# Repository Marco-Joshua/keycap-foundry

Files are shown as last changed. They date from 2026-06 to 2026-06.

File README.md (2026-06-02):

# Keycap Foundry

Parametric MX-compatible keycap library designed for **lost-wax silver casting**.
Written in OpenSCAD, validated with `trimesh`, previewed in a Three.js gallery.

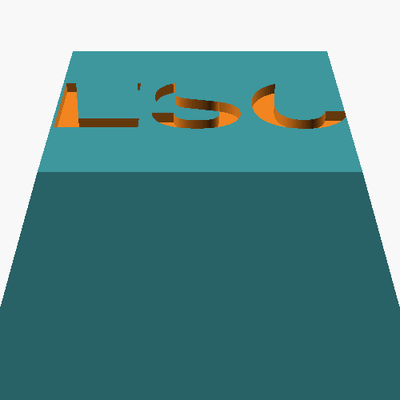
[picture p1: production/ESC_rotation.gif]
ESC keycap rotation


## 사용법 (한국어 요약)

OpenSCAD 기반 파라메트릭 실버 키캡 라이브러리. **MX 호환 키캡을 코드 한 줄 바꿔서 다시 뽑고, 화면에서 보고, 주물업체에 보낼 STL/도면까지 한 번에 만들어줍니다.**

### 1. 설치 (최초 1회)
```bash
brew install --cask openscad@snapshot           # ARM Mac 네이티브
python3 -m pip install --user numpy trimesh
```

### 2. 갤러리에서 미리 만들어진 디자인 보기
```bash
python3 -m http.server 8765
# 브라우저에서 http://localhost:8765/ 열기
```
- **ESC 키캡 (production)** 탭 — 본 발주용. 1.0mm wall(안전)·0.8mm wall(절감) 비교
- **평평한 윗면** 탭 — 같은 디자인 다른 벽 두께
- **단면 (내부 구조)** 탭 — 무광 + 검은 엣지로 내부 구조 시각화
- 하단 뷰 버튼으로 **정면·위·아래·옆** 전환 가능

### 3. 새 키캡 만들기
`keycap.scad`는 안 만지고 변수만 바꿔서 호출하면 됩니다:
```bash
# 예: "Enter" 2.25u, 1.0mm wall, 평평한 윗면, hollow, 캐스팅 보정 1.8%
openscad \
  -D 'flat_top=true' -D 'hollow=true' -D 'wall_thickness=1.0' \
  -D 'profile="cherry"' -D 'row=2' -D 'key_units=2.25' \
  -D 'legend="Enter"' -D 'legend_size=4.5' \
  -D 'shrink_compensation=1.018' \
  -o Enter_cast.stl keycap.scad
```
주요 변수는 아래 [Key parameters](#key-parameters-keycapscad) 표 참고.

### 4. STL 검증 + 실버 무게·원가 계산
```bash
python3 analyze.py Enter_cast.stl
# → manifold 확인, 부피, 925/999 무게, 예상 재료비 (₩1,500/g 기준)
```

### 5. 주물업체에 보낼 것
| 파일 | 용도 |
|---|---|
| `production/spec_sheet.html` | 브라우저에서 ⌘+P → PDF로 저장 → A4 도면 |
| `production/*_cast.stl` | **이 파일을 발주** (1.8% 업스케일 = 캐스팅 후 실치수) |
| `production/ESC_rotation.gif` | 카톡으로 "이런 거 가능한가요?" 미리보기 |

### 6. 디자인 바꾸고 갤러리에 반영
```bash
# 새 STL을 out/ 또는 production/에 넣고
python3 build_manifest.py    # → manifest.json 다시 빌드
# 브라우저 새로고침
```
갤러리에 노출할 항목은 `build_manifest.py`의 `ITEMS` 리스트에 추가합니다.

### 캐스팅 흐름
**시험 (PLA 출력)** → 동네 출력소 ₩3~5천, `*_design.stl` 사용, 키보드에 끼워봄
↓
**견적 의뢰** → 종로 주얼리 거리 주물업체, `*_cast.stl` + spec sheet PDF + GIF 전달
↓
**본 발주** → 캐스터블 레진 출력 → 로스트왁스 → 폴리싱 → (선택) 로듐 도금

---

## What this is

A code-defined keycap that you can:
- regenerate at any size (1u, 1.25u, ..., 6.25u spacebar)
- engrave with any text (currently Helvetica Bold, easily swappable)
- hollow with a uniform wall (default 1.0 mm, configurable down to 0.8 mm)
- export as a watertight, manifold STL ready for casting

The included `production/` folder ships an **ESC keycap** (1u, flat top, Cherry R1
height, Hollow 1.0mm wall) — both at design dimensions and with **+1.8% shrink
compensation** applied for silver lost-wax casting.

## Why parametric over CAD

Keycaps need precision (the MX cross slot is 0.05 mm tolerance) but very little
artistic curvature. That makes them a perfect fit for code-defined modelling:
change a variable, rebuild in 100 ms. No CAD license, no GUI clicks.

## Layout

```
keycap.scad          Parametric library (single file, all features)
analyze.py           STL → manifold check + volume + silver weight + cost
build_manifest.py    Regenerate manifest.json for the gallery
gallery.html         Three.js viewer with 4 view presets (front/top/bottom/iso)
index.html           Landing page → links to gallery, spec sheet, GIF, slicer guide
out/                 Generic flat-top hollow demos (1.0 & 0.8 mm wall)
production/          ESC keycap deliverable set
  ├── *_design.stl   Exact dimensions — for slicer / PLA test print
  ├── *_cast.stl     +1.8% upscale — what you give to the silver caster
  ├── *_cutaway.stl  Half-section for showing internal structure
  ├── spec_sheet.html  Printable A4 dimension drawing (browser → PDF)
  ├── ESC_rotation.gif  3-second 360° preview
  ├── ESC_SPEC.md    Plain-text spec (for email body)
  └── SLICER_CHECK.md  Pre-print checklist for FDM / resin
```

## Quick start

```bash
# Prerequisites
brew install --cask openscad@snapshot      # ARM-native OpenSCAD
python3 -m pip install --user numpy trimesh

# Generate an ESC keycap
openscad \
  -D 'flat_top=true' -D 'hollow=true' -D 'wall_thickness=1.0' \
  -D 'profile="cherry"' -D 'row=1' -D 'legend="ESC"' -D 'legend_size=4.5' \
  -o ESC.stl keycap.scad

# Validate + estimate silver weight & cost
python3 analyze.py ESC.stl

# Preview the gallery
python3 -m http.server 8765
# → open http://localhost:8765/
```

## Key parameters (`keycap.scad`)

| Parameter | Default | Notes |
|---|---|---|
| `key_units` | `1.0` | 1, 1.25, 1.5, 1.75, 2, 2.25, 6.25 |
| `profile` | `"cherry"` | `cherry` · `oem` · `sa` · `dsa` · `xda` |
| `row` | `3` | R1..R4 — only affects height on sculpted profiles |
| `hollow` | `false` | Open-bottom hollow shell with + stem |
| `wall_thickness` | `1.0` | Uniform wall (sides + top); 0.6 mm castable minimum |
| `flat_top` | `false` | Override the profile dish for a fully flat top |
| `legend` | `""` | Text to engrave (empty = none) |
| `legend_size` | `7` | Font height in mm |
| `legend_depth` | `0.45` | Engrave depth in mm |
| `shrink_compensation` | `1.0` | Use `1.018` for silver casting (1.8% upscale) |
| `cutaway` | `false` | Slice in half along XZ plane (for visualization) |

## Casting workflow

1. Open `production/spec_sheet.html` in a browser, print → PDF.
2. PLA-print `*_design.stl` at a local print shop (~₩3–5k) → fit on an MX
   switch, verify dimensions.
3. Hand the silver caster the `*_cast.stl` file + the spec sheet PDF.
   Common path in Korea: 종로 주얼리 거리's lost-wax casters (₩20–50k/cap
   casting fee on top of silver material cost).
4. Optional: rhodium plating to prevent tarnish (~₩5–10k/cap).

## Design choices

- **Open bottom** — required so wax can drain during burnout and silver can
  fill cleanly. Also standard for injection-molded keycaps.
- **+-shaped stem with no end caps** — minimum material, matches the standard
  4-pillar layout you see in commercial cast/plated keycaps.
- **Uniform wall** — top wall follows the dish curve (or stays flat) so the
  wall is exactly `wall_thickness` everywhere — easier for casters to quote.
- **Cross slot extended to underside of top wall** — saves material in the
  stem while still grabbing the MX switch via the full 4 mm cross arms.

## License

MIT — see [LICENSE](LICENSE). Use, modify, sell, fork — go ahead.

## Acknowledgements

- Reference for MX dimensions and standard keycap construction:
  [rsheldiii/KeyV2](https://github.com/rsheldiii/KeyV2)
- Built with Claude Code (Opus 4.7) — see commit log for the design iteration.

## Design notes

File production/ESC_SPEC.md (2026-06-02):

# ESC 키캡 발주 명세 (Silver)

## 기본 정보
| 항목 | 값 |
|---|---|
| **키** | ESC |
| **각인** | "ESC" (음각, 4.5mm Helvetica Bold, 0.45mm 깊이) |
| **소재** | 순은 (999) 또는 스털링 실버 (925) |
| **마감** | 폴리싱 + (선택) 로듐 도금 |
| **공법** | Lost-wax casting |

## 치수 (최종 캐스팅 후 기준)
| 항목 | 값 |
|---|---|
| 가로 × 세로 | 18.10 × 18.10 mm (1u, Cherry profile) |
| 높이 | 9.40 mm (Cherry Row 1, F-row 호환) |
| 윗면 | **평평** (dish 없음) |
| 벽 두께 | 1.0 mm (균일, 측면·천장 모두) |
| Stem | + 자형, 4개 코너 필러 구조 (사진/사출 표준) |
| 십자 슬롯 | 4.10 × 1.27 mm, 깊이 ~5.5mm (top wall 직전까지) |
| 바닥 | 개방 (왁스 배출 가능) |

## 무게 / 원가
| 항목 | Sterling (925) | Fine (999) |
|---|---|---|
| 무게 | 7.83 g | 7.91 g |
| 재료비 (₩1,500/g 기준) | ≈ ₩11,750 | ≈ ₩11,870 |
| + 캐스팅·후처리 (예상) | ₩20,000 ~ ₩50,000 | — |

## 캐스팅 수축 보정
- **DESIGN STL**: 정확한 최종 치수 (18.10mm, 9.40mm). 3D 프린트 검증·MX 스위치 적합성 확인용.
- **CAST STL**: 1.8% 업스케일 (18.43mm, 9.57mm). 주물업체에 이 파일로 발주. 캐스팅 수축 후 DESIGN 치수로 수렴.

## 파일
| 파일 | 용도 |
|---|---|
| `ESC_1u_flat_hollow_1.0mm_design.stl` | 슬라이서 검증·시험 출력·MX 호환성 |
| `ESC_1u_flat_hollow_1.0mm_cast.stl` | 캐스터블 레진 출력 → 주물 의뢰 |
| `ESC_1u_cutaway.stl` | 내부 구조 설명용 (단면) |
| `preview_iso.png` | 아이소뷰 (캡 전체) |
| `preview_top.png` | 톱뷰 ("ESC" 각인 확인) |
| `preview_bottom.png` | 바텀뷰 (+ stem, 4개 코너 필러) |
| `preview_cutaway.png` | 단면도 (내부 캐비티) |

## 메시 검증
- ✅ Watertight (수밀)
- ✅ Manifold (매니폴드)
- ✅ Volume valid (부피 계산 정상)

## 주물업체에 전달 시 핵심 포인트
1. **벽 두께 1.0mm 균일** — 모든 wall이 1mm. 캐스팅 한계 안에 있음
2. **바닥 개방형** — 왁스 배출 + 사일버 주입 둘 다 용이
3. **십자 슬롯 dimensions**: 4.10 × 1.27 × 4.0mm 깊이 — Cherry MX 호환
4. **수축 보정 STL** 사용 (`_cast.stl` 파일)
5. 후처리: 십자 슬롯 내부 폴리싱 주의 (스위치 결합 부위)

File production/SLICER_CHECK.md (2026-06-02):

# 슬라이서 검증 가이드 (PLA·캐스터블 레진 출력 전)

## 빠른 체크 (5분)

### 1. 슬라이서에 STL 열기
- **PLA 출력 (시험용, FDM)**: Bambu Studio · Prusa Slicer · Cura
- **캐스터블 레진 출력 (주물용, SLA/DLP)**: Chitubox · Lychee Slicer · Bambu Studio (Bambu Lab A1/X1 + 레진 어댑터)

파일: `ESC_1u_flat_hollow_1.0mm_design.stl` (시험용) 또는 `_cast.stl` (수축 보정본)

### 2. 자동 점검할 항목
| 점검 | 정상 기준 | 문제 신호 |
|---|---|---|
| **Manifold (수밀성)** | "No errors" / 초록 체크 | "Non-manifold edges" 빨간 경고 → STL 손상 |
| **Wall thickness** | 1.0 mm 균일 | 0.4 mm 이하 영역 발견 시 강도 부족 경고 |
| **Inverted normals** | 없음 | 보라색/뒤집힌 면 있으면 STL 손상 |
| **Mesh repair** | "No repair needed" | "Auto-repair" 메시지 뜨면 우리 STL 문제 — 다시 export 필요 |

### 3. 출력 방향 (Orientation)
- **권장**: 바닥(MX 십자 슬롯)이 **위쪽**을 향하게 거꾸로 세움
  - 이유: 바닥이 개방형이라 서포트 거의 불필요, 윗면(ESC 각인)은 빌드 플레이트 쪽이라 매끈히 출력됨
- 측면 출력은 비추천 (사면이 모두 경사라 서포트 많이 필요)

### 4. 서포트 설정
- **FDM (PLA)**: 십자 슬롯 안쪽에 미세한 서포트 자동 생성될 수 있음. 출력 후 제거 가능
- **레진 (캐스터블)**: 외부 표면에만 가는 서포트 (0.4mm), 매끈한 면은 위쪽으로

### 5. 인쇄 설정 권장
**FDM 시험 출력 (PLA)**:
- Nozzle: 0.4 mm
- Layer: 0.16 mm
- Walls: 4 perimeters (실리콘 키캡과 흡사한 두께감)
- Infill: 25% (시험용이므로 가벼우면 됨)
- Time: ~30분 ~ 1시간 / cap

**캐스터블 레진 (주물 의뢰용)**:
- Layer: 0.05 mm (정밀)
- Resin: 캐스터블 (Castable wax-based) — Phrozen Wax Resin / Siraya Tech Cast
- 출력 후 burnout 가능한 잔여물 없는 종류
- Time: ~1시간 / cap

## 예상되는 경고 & 대응

| 경고 | 의미 | 대응 |
|---|---|---|
| "Wall under 0.5mm" | 일부 구간 wall thin | 우리 디자인은 0.7mm 최소 — 무시 OK |
| "Overhangs detected" | 일부 면이 45° 이상 경사 | 측면 경사 (top_inset 3mm) — 서포트 자동 처리 |
| "Multiple shells" | 분리된 메시 발견 | + stem의 4 pillar는 top wall로 연결되어 있음 — 정상 |
| "Mesh has gaps" | 진짜 STL 손상 | 우리 STL은 watertight 검증됨 — 다시 export |

## 확인 후 다음 단계

✓ 슬라이서 통과 → PLA 시험 출력 또는 캐스터블 레진 출력 의뢰
✗ 경고 떠도 무시 가능한 항목이면 진행, 아니면 keycap.scad에서 파라미터 조정 후 re-export

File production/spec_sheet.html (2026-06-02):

# ESC 키캡 — Silver Cast 발주 명세서

Cherry MX 호환 · 1u Row-1 · 평평한 윗면 · Hollow · Lost-Wax 캐스팅

키ESC

사이즈1u (18.10 × 18.10 mm)

높이9.40 mm (Cherry R1)

윗면평평 (no dish)

벽 두께1.0 mm 균일

Stem+ 4-pillar (MX 표준)

소재순은(999) 또는 스털링(925)

공법Lost-wax casting

예상 무게7.91 g (999)

재료비 (₩1,500/g)≈ ₩11,800

캐스팅 수축 보정+1.8% (설계 STL 포함)

마감폴리싱 · (선택) 로듐 도금

## 도면 — 4면 + 단면

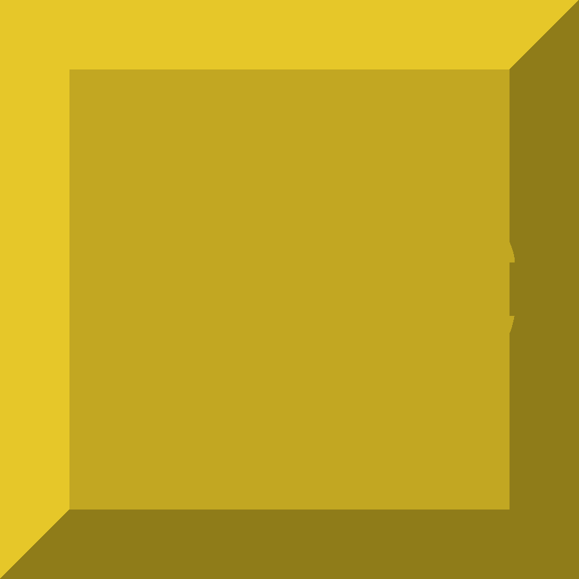
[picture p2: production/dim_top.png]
Top


TOP (위에서)

18.10 × 18.10 mm

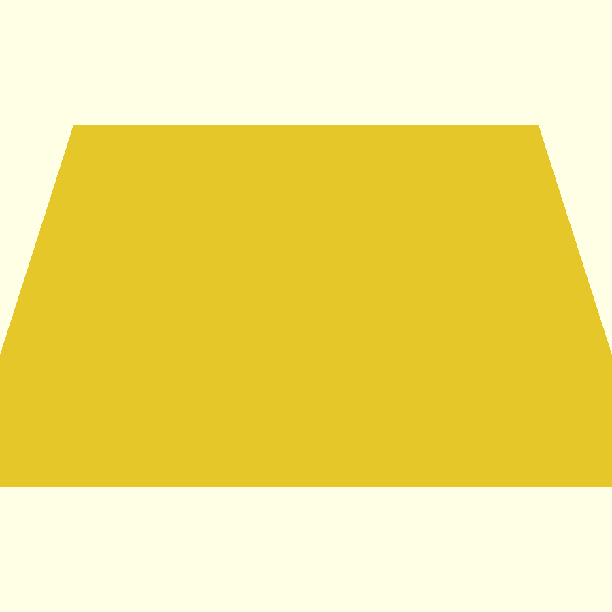
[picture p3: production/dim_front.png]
Front


FRONT (정면)

높이 9.40 mm

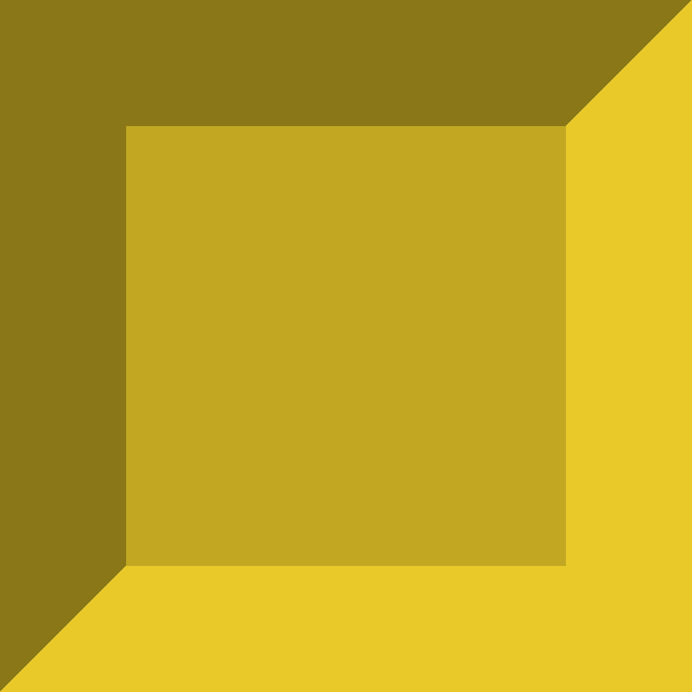
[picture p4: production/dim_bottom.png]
Bottom


BOTTOM (아래에서)

+ stem, 십자 슬롯

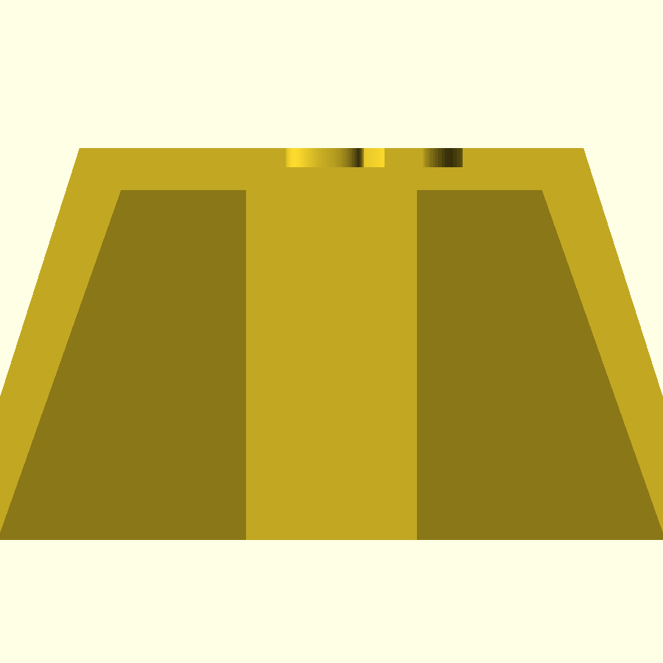
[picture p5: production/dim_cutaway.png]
Section


SECTION (단면)

wall 1.0 mm 균일

## 주요 치수 (Cast 후 최종 목표)

항목 | 설계값 | Cast STL (1.8%↑) | 비고
가로 (X) | 18.10 mm | 18.43 mm | 1u 표준 키 피치 19.05 − gap 0.95
세로 (Y) | 18.10 mm | 18.43 mm | 1u 표준
높이 (Z) | 9.40 mm | 9.57 mm | Cherry profile R1 (F-row 매칭)
윗면 사이즈 | 12.10 × 12.10 mm | 12.32 × 12.32 mm | top inset 3.0 mm
측면·천장 벽 두께 | 1.00 mm | 1.02 mm | 전체 균일
각인 "ESC" | 4.5 mm font, 0.45 mm 깊이 | − | Helvetica Bold, 음각
MX 십자 슬롯 (장) | 4.10 mm | 4.17 mm | Cherry MX stem 4.0 mm + 여유 0.10
MX 십자 슬롯 (단) | 1.27 mm | 1.29 mm | MX stem 1.17 mm + 여유 0.10
십자 슬롯 깊이 | ~5.5 mm | ~5.6 mm | 천장 wall까지 (0.4 mm 캡 잔류)
Stem boss 외곽 (장) | 4.10 mm | 4.17 mm | + 4-pillar 구조
Stem boss 외곽 (단) | 2.67 mm | 2.72 mm | 슬롯 양옆 wall 0.70 mm
바닥 | 개방 | 개방 | 왁스 배출 가능

## 캐스팅 작업 메모

- 발주 시 사용 파일: ESC_1u_flat_hollow_1.0mm_cast.stl (수축 보정본)
- 벽 두께 1.0 mm는 925 sterling silver lost-wax 캐스팅 가능 범위 내. 부분적으로 0.7 mm까지 좁아지는 십자 슬롯 옆 wall이 가장 얇은 부분 — 무리 없이 가능.
- 바닥 개방형이므로 왁스/레진 배출 + 은 주입에 별도 vent 불필요.
- 후처리: 외부 폴리싱 후, MX 십자 슬롯 내부는 폴리싱하지 말 것 (스위치 결합 부위, 표면 다소 거칠어야 그립 양호).
- 치수 검증: 캐스팅 후 십자 슬롯 사이즈 (4.0 × 1.17 mm 이상 1.20 × 4.05 이하) 확인 필요. 너무 빡빡하면 MX 스위치 결합 어렵고, 너무 헐거우면 키캡 뽑힘.
- 변색 방지: 손가락 접촉 면이라 시간 지나면 황변 가능. 로듐 도금 권장 (캡당 ₩5,000~10,000 추가).

## 파일 (production/)

ESC_1u_flat_hollow_1.0mm_design.stl슬라이서 검증·PLA 시험 출력·MX 호환성 확인용

ESC_1u_flat_hollow_1.0mm_cast.stl★ 주물업체 발주용 (1.8% 업스케일)

ESC_1u_cutaway.stl내부 구조 설명용 (단면)

ESC_1u_flat_hollow_0.8mm_design.stl대안: 더 얇은 벽 (6.60g)

ESC_1u_flat_hollow_0.8mm_cast.stl대안 발주용

ESC_rotation.gif360° 회전 미리보기 (캐스터에 카톡 전송용)

생성: OpenSCAD 2026.04.26 → STL (manifold, watertight 검증) → trimesh 분석

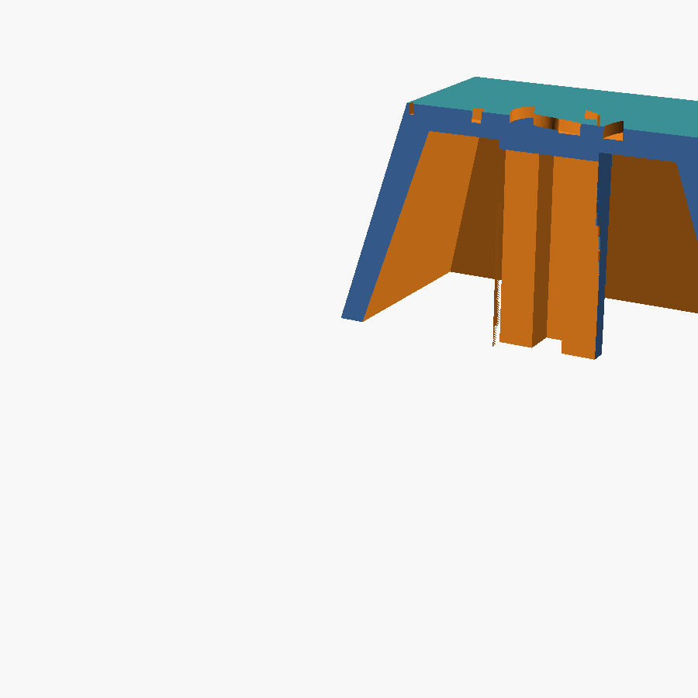
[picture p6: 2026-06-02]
production/preview_cutaway.png

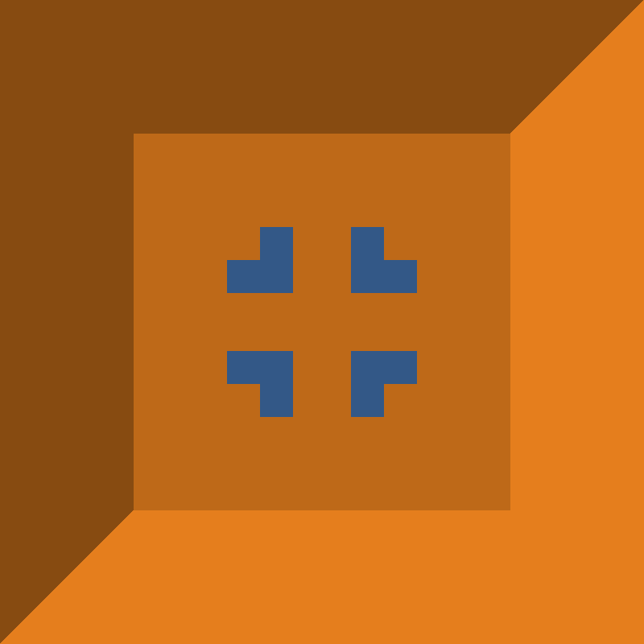
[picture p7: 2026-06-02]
production/preview_bottom.png

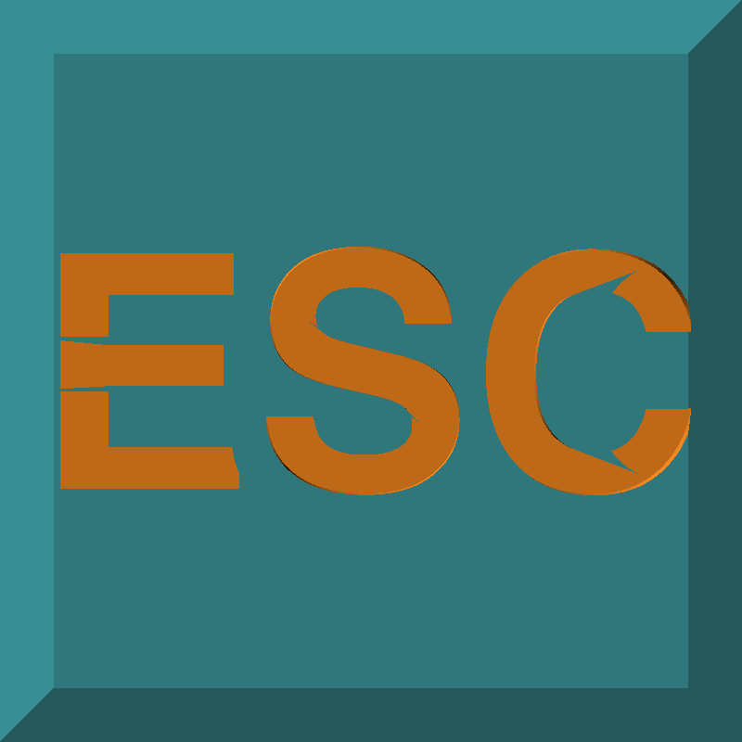
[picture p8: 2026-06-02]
production/preview_top.png

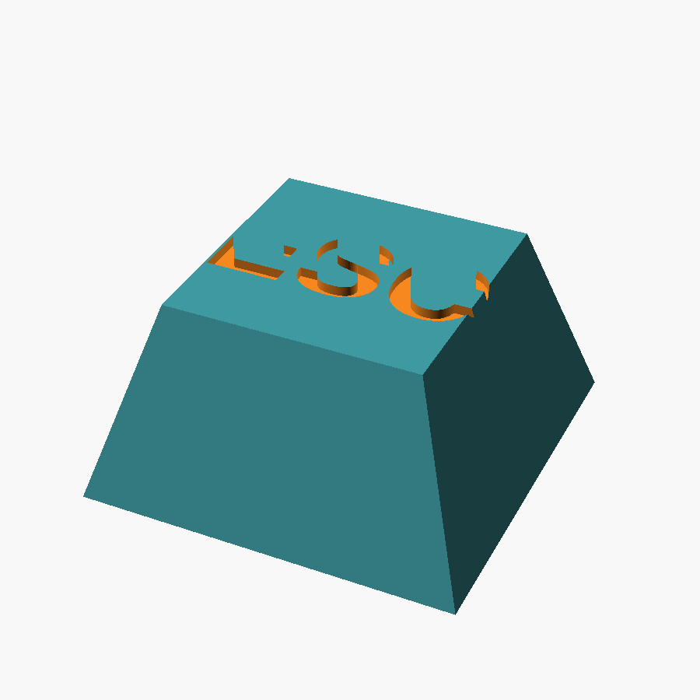
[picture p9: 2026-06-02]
production/preview_iso.png

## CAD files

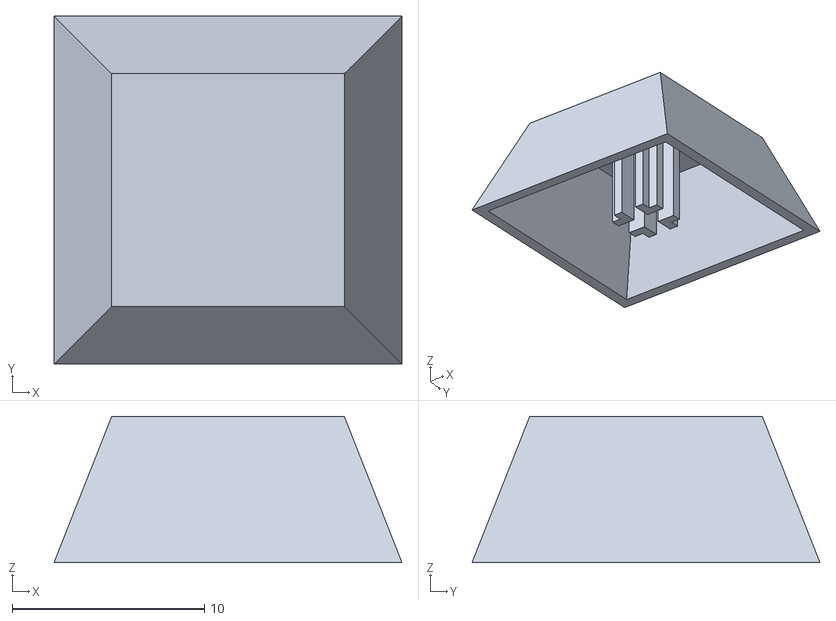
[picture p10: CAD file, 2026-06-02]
out/flat_1u_hollow_thin.stl
18.1 x 18.1 x 7.60

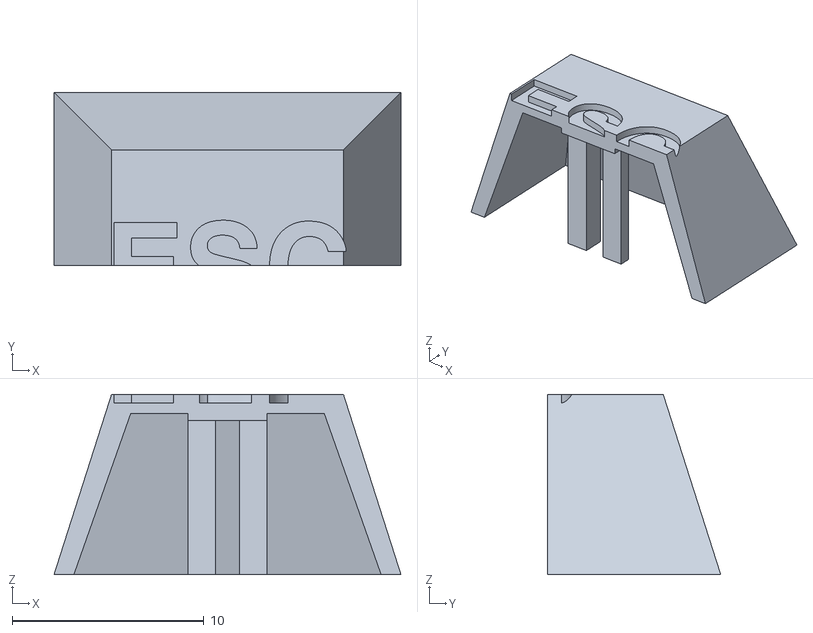
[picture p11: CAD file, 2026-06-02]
production/ESC_1u_cutaway.stl
18.1 x 9.05 x 9.40

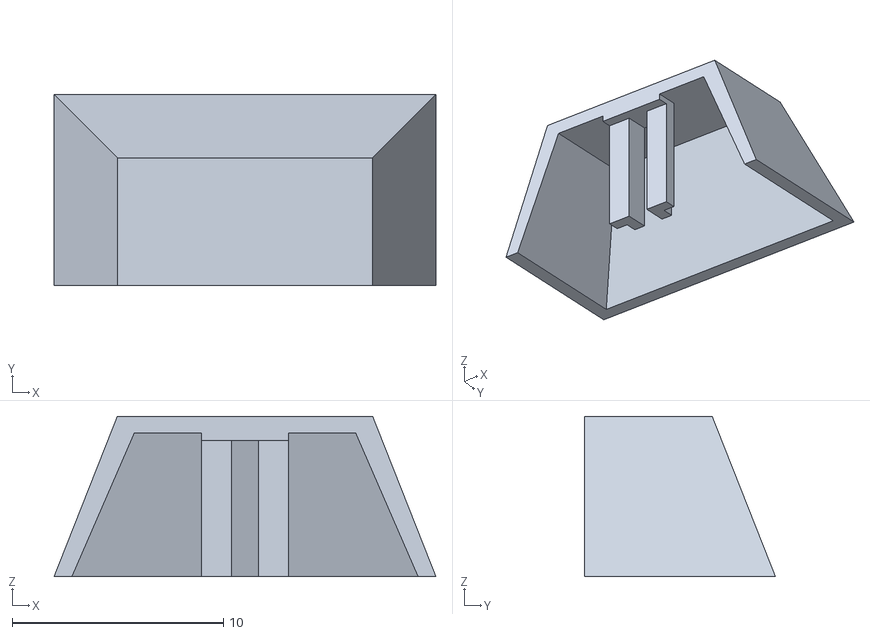
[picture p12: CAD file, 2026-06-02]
out/flat_cutaway_hollow_thin.stl
18.1 x 9.05 x 7.60

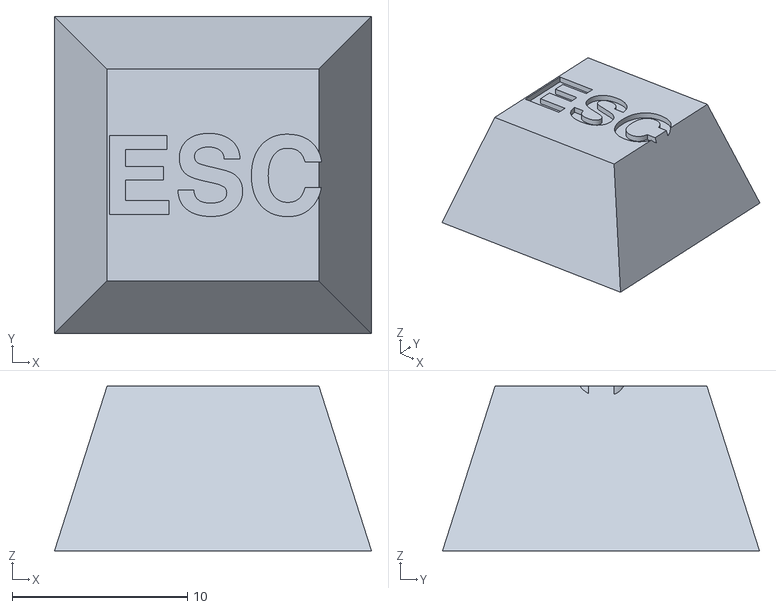
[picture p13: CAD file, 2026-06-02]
production/ESC_1u_flat_hollow_1.0mm_design.stl
18.1 x 18.1 x 9.40

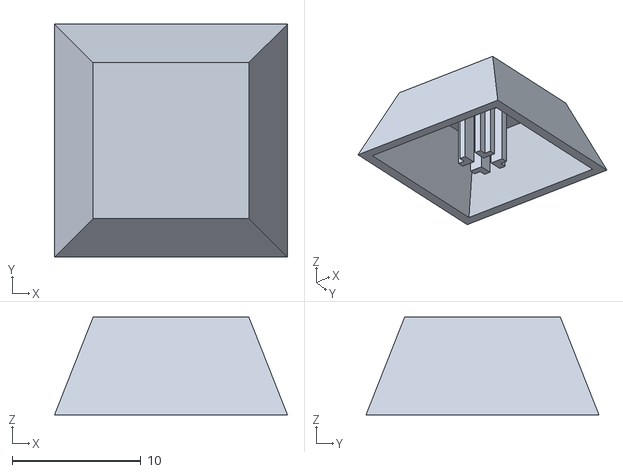
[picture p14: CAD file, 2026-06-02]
out/flat_1u_hollow.stl
18.1 x 18.1 x 7.60

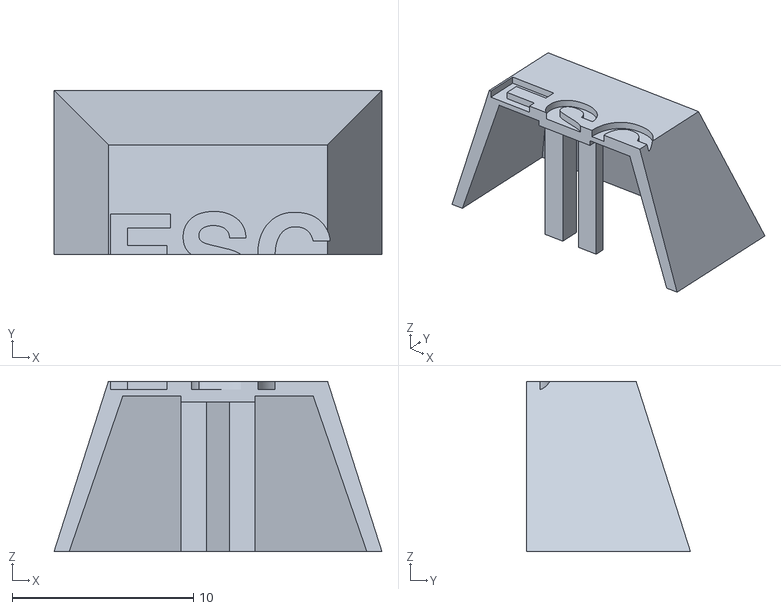
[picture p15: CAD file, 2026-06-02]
production/ESC_1u_cutaway_0.8mm.stl
18.1 x 9.05 x 9.40

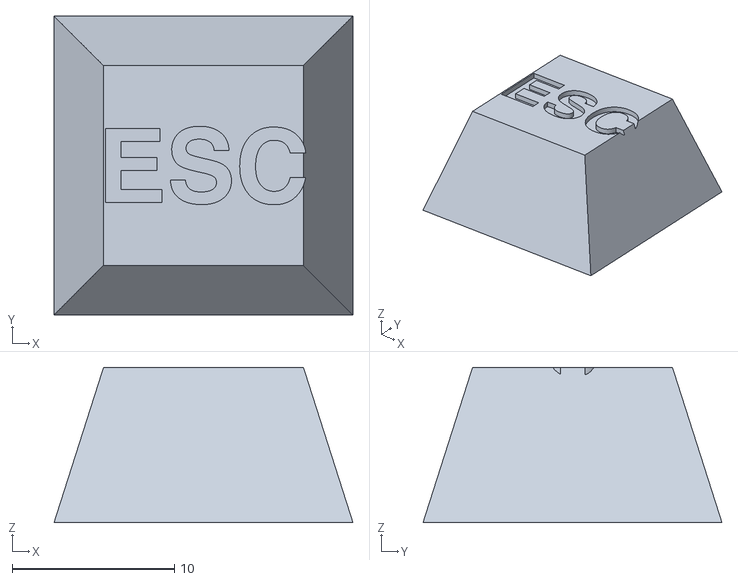
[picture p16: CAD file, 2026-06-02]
production/ESC_1u_flat_hollow_0.8mm_cast.stl
18.4 x 18.4 x 9.57

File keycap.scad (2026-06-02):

// =====================================================
// Parametric Silver Keycap Library
// Features: hollow, legend engraving, multi-size, 5 profiles
// Units: millimeters
// =====================================================

// ---- Top-level parameters (override via openscad -D) ----
key_units      = 1.0;        // 1, 1.25, 1.5, 1.75, 2, 2.25, 2.75, 6.25
profile        = "cherry";   // "cherry" | "oem" | "sa" | "dsa" | "xda"
row            = 3;          // R1..R4 — only used by sculpted profiles
hollow         = false;
wall_thickness = 1.0;        // outer wall + top wall; minimum castable in 925 silver ≈ 0.6mm
legend         = "";         // "" = no engraving
legend_depth   = 0.45;
legend_size    = 7;
legend_font    = "Helvetica:style=Bold";
cutaway        = false;      // true → cut in half along XZ plane (y>=0 kept)
flat_top       = false;      // true → no dish curvature on top (overrides profile dish)
shrink_compensation = 1.0;   // scale factor: 1.018 ≈ 1.8% upscale for silver casting shrinkage

// ---- Constants ----
unit_pitch     = 19.05;
gap            = 0.95;
cross_w        = 4.10;
cross_t        = 1.27;
cross_d        = 4.0;
stem_wall      = 0.7;        // side wall around the cross slot (perpendicular to arm)
stem_arm_long  = cross_w;                  // 4.10mm — stem arm length = cross arm length (NO end caps)
stem_arm_short = cross_t + 2 * stem_wall;  // 2.67mm — side walls only
stab_off_2u    = 11.94;
stab_off_625   = 50.0;
stab_off_7u    = 57.0;

$fn = 96;

// ---- Profile registry ----
function spec(p, r) =
    p == "cherry" ? [ r == 1 ? 9.4 : r == 2 ? 8.7 : r == 3 ? 7.6 : 7.6,
                      3.0, 35, 0.7, "cyl" ]
  : p == "oem"    ? [ r == 1 ? 11.9 : r == 2 ? 11.0 : r == 3 ? 9.8 : 10.6,
                      3.0, 50, 0.7, "cyl" ]
  : p == "sa"     ? [ r == 1 ? 12.9 : r == 2 ? 12.0 : r == 3 ? 11.4 : 12.6,
                      4.5, 22, 1.5, "sph" ]
  : p == "dsa"    ? [ 7.4, 4.0, 22, 1.0, "sph" ]
  : p == "xda"    ? [ 9.2, 2.5, 26, 0.9, "sph" ]
  :                 [ 9.5, 3.0, 35, 0.7, "cyl" ];

specs    = spec(profile, row);
height   = specs[0];
top_in   = specs[1];
dish_r   = specs[2];
dish_d   = flat_top ? 0 : specs[3];
dish_typ = specs[4];

base_x = key_units * unit_pitch - gap;
base_y = unit_pitch - gap;
top_x  = base_x - 2 * top_in;
top_y  = base_y - 2 * top_in;

// ---- Modules ----
module outer_shell() {
    hull() {
        translate([0, 0, 0.001])         cube([base_x, base_y, 0.002], center=true);
        translate([0, 0, height - 0.001]) cube([top_x, top_y, 0.002], center=true);
    }
}

module inner_void() {
    // Open-bottom cavity with UNIFORM wall_thickness everywhere — top wall follows dish curvature.
    // Construction: base frustum extends up to (height - wall_thickness) at edges, then a
    // shifted dish-shape (offset down by wall_thickness) carves the curve into the ceiling.
    void_top_flat = height - wall_thickness;
    if (void_top_flat > 0.5) {
        difference() {
            hull() {
                translate([0, 0, -0.1])
                    cube([max(base_x - 2*wall_thickness, 1), max(base_y - 2*wall_thickness, 1), 0.001], center=true);
                translate([0, 0, void_top_flat])
                    cube([max(top_x - 2*wall_thickness, 1), max(top_y - 2*wall_thickness, 1), 0.001], center=true);
            }
            if (dish_d > 0) {
                if (dish_typ == "cyl") {
                    translate([0, 0, height - dish_d + dish_r - wall_thickness])
                        rotate([90, 0, 0])
                            cylinder(r=dish_r, h=base_y * 3, center=true);
                } else {
                    translate([0, 0, height - dish_d + dish_r - wall_thickness])
                        sphere(r=dish_r);
                }
            }
        }
    }
}

module dish_neg() {
    if (dish_d > 0) {
        if (dish_typ == "cyl") {
            translate([0, 0, height - dish_d + dish_r])
                rotate([90, 0, 0])
                    cylinder(r=dish_r, h=base_y * 3, center=true);
        } else {
            translate([0, 0, height - dish_d + dish_r])
                sphere(r=dish_r);
        }
    }
}

module mx_cross_neg() {
    // Hollow caps: cross extends nearly to underside of top wall (matches injection-molded keycap norm).
    // Solid caps: keep standard 4mm depth.
    ch = hollow ? (height - dish_d - wall_thickness - 0.4) : cross_d;
    translate([0, 0, -0.05])
        union() {
            translate([-cross_w/2, -cross_t/2, 0])
                cube([cross_w, cross_t, ch + 0.1]);
            translate([-cross_t/2, -cross_w/2, 0])
                cube([cross_t, cross_w, ch + 0.1]);
        }
}

module stem_boss_pos() {
    // "+" stem with side walls only — no end caps at the arm tips.
    // Arm length matches the cross slot exactly; side walls are 0.7mm thick.
    h = height - dish_d - wall_thickness + 0.6;
    union() {
        translate([-stem_arm_long/2, -stem_arm_short/2, 0])
            cube([stem_arm_long, stem_arm_short, h]);
        translate([-stem_arm_short/2, -stem_arm_long/2, 0])
            cube([stem_arm_short, stem_arm_long, h]);
    }
}

module stabilizers(units) {
    off = units >= 7    ? stab_off_7u
        : units >= 6.25 ? stab_off_625
        : units >= 2    ? stab_off_2u
        : 0;
    if (off > 0) {
        translate([ off, 0, 0]) children();
        translate([-off, 0, 0]) children();
    }
}

module legend_neg() {
    if (len(legend) > 0) {
        // place text-cutting prism above the keycap, extending down past dish bottom
        // by `legend_depth`, so engraving depth ≈ legend_depth measured from top surface
        translate([0, 0, height - dish_d - legend_depth])
            linear_extrude(height)
                text(legend, size=legend_size, font=legend_font,
                     halign="center", valign="center");
    }
}

module keycap() {
    difference() {
        union() {
            difference() {
                outer_shell();
                dish_neg();
                if (hollow) inner_void();
            }
            // re-add solid stem boss for hollow caps so MX stem grips
            if (hollow) {
                stem_boss_pos();
                stabilizers(key_units) stem_boss_pos();
            }
        }
        mx_cross_neg();
        stabilizers(key_units) mx_cross_neg();
        legend_neg();
    }
}

scale([shrink_compensation, shrink_compensation, shrink_compensation]) {
    if (cutaway) {
        intersection() {
            keycap();
            translate([0, 100, 0])
                cube([500, 200, 200], center=true);
        }
    } else {
        keycap();
    }
}

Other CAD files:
out/flat_cutaway_hollow.stl
production/ESC_1u_flat_hollow_0.8mm_design.stl
production/ESC_1u_flat_hollow_1.0mm_cast.stl

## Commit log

2026-06-02 Initial commit: parametric silver keycap library + ESC production set
    - keycap.scad: parametric library supporting 5 profiles, multi-size, hollow with
    open bottom, uniform 1mm wall (dish-following ceiling), + 4-pillar stem, MX
    cross slot extending to top wall, legend engraving, casting shrinkage
    compensation.
    - ESC keycap production set (1u, flat top, Cherry R1 height, hollow):
    * 1.0mm wall: 7.91g design / 8.34g cast (recommended)
    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
    [ESC_1u_cutaway.stl, ESC_1u_cutaway_0.8mm.stl, ESC_1u_flat_hollow_0.8mm_cast.stl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]
2026-06-02 docs: 한국어 사용법 요약 추가 (README)
    설치 → 갤러리 → 새 키캡 생성 → 검증 → 주물업체 발주 → 갤러리 갱신까지
    6단계 흐름으로 정리. 캐스팅 워크플로우도 한 줄로 요약.
